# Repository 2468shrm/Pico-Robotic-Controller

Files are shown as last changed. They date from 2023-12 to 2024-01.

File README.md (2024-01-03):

# Pico-Robotic-Controller

A carrier board for a Raspberry Pi Pico (W) for use in FRC robotics. Similar
to the XRP board.

## Disclaimer / Warning

This is an experimental device. Not all interfaces have been fully validated
for proper function. Use at your own risk.

## Introduction (Motivation)

You may assume that this board is indended to compete with the XRP product
from WPI, other developers, and SparkFun. __It is not__. The XRP board is
awesome and I'll likely end up acquiring one (or two) for myself. I have
been working on lo w-cost, roboRIO-like carrier boards for FRC for a couple
of years.

Why create a carrier board like the roboRIO? To enable a lower-cost
prototyping solution. This solution makes it less risky to a costly
than using a roboRIO solution. Breaking a roboRIO means costly replacement
that is sometimes hard to replace. One goal was to provide as many
similar interfaces as possible but cost 25% the budget.

Things I didn't need to do with my use model: support LabVIEW despite being
a team who lives and breaths LabVIEW. I did want to support rapid prototyping
and so exploring circuitpython was a goal; particularly because of the
library support for the STEMMA QT/Qwiic based sensors available from
Adafruit.

## Board Images

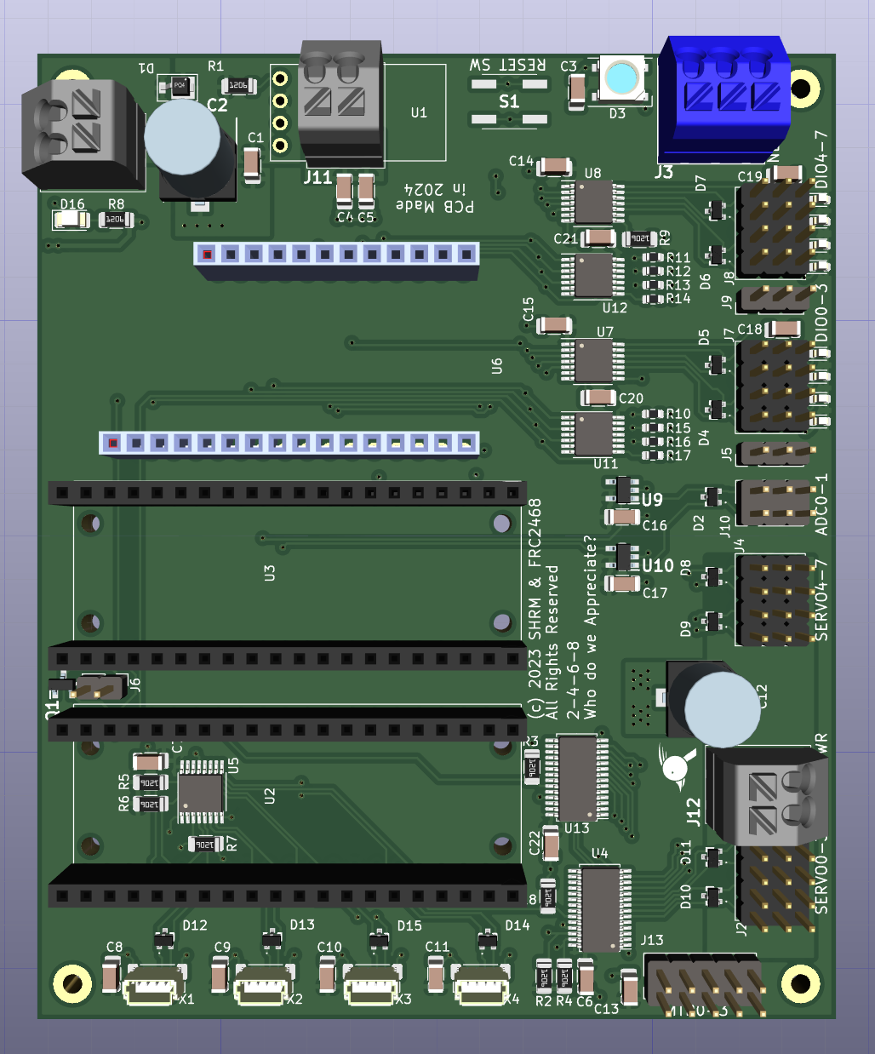
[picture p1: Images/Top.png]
Top View


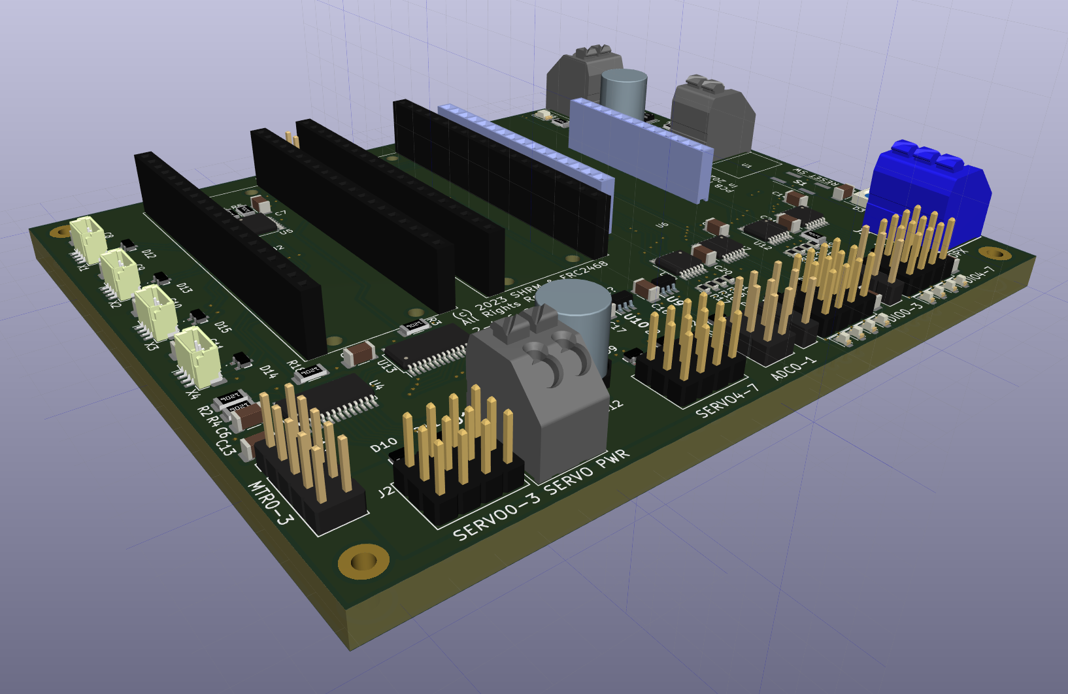
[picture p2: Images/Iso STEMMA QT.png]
Isometric View from the I2C connector corner


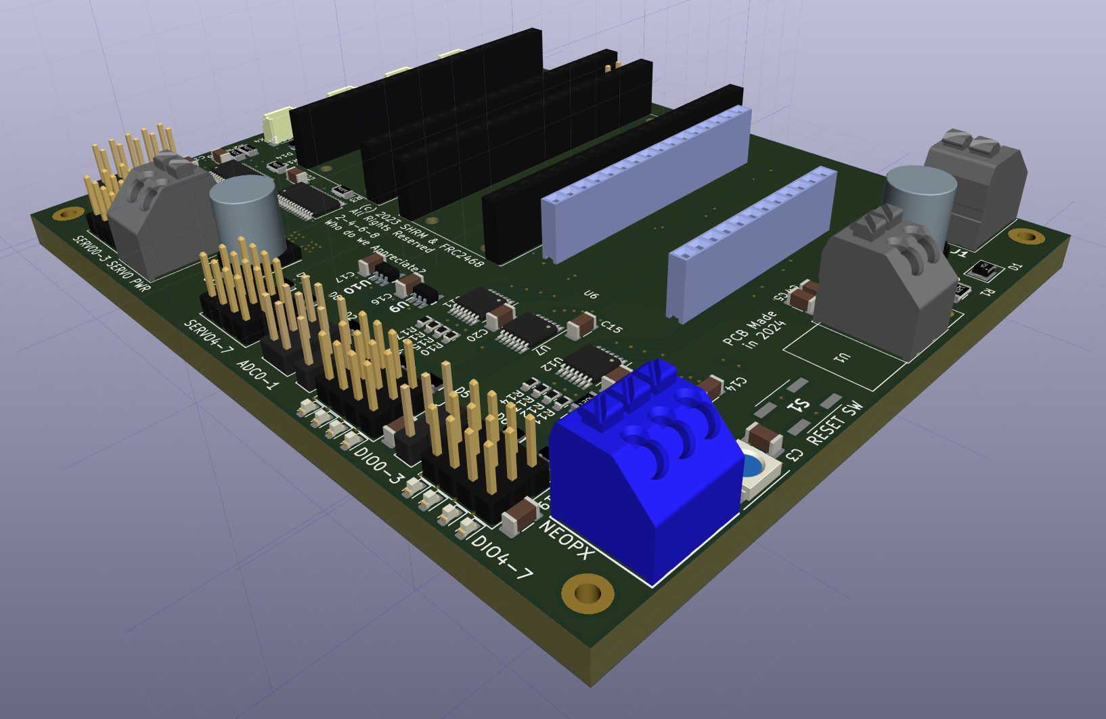
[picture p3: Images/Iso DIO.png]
Isometric View from the digital I/O connector corner


## Board Features

The carrier board has the following interfaces and features.

- RaspberryPi Pico W board
  - Does the thinking
  - Provides WiFi and/or Bluetooth
  - Socketed for replacemnt if needed
- Adafruit Picobell CAN board (optional)
  - Provides CAN connectivity for integration into FRC robots allowing CAN-connected applications (e.g. smart sensors)
- Adafruit Ethernet Featherwing board (optional)
  - Provides Ethernet connectivity for integration into FRC robots allowing Ethernet connected applications (e.g. smart sensors)
- Power
  - 12V Battery input provides main board supply
    - 5V regulator module, OR
    - A connection to external 5V regulator (using WAGO 250-202) connector if the 5V supply current requirements are higher than the module can provide
  - Servo/PWM interface independently powered by an external source
    - Due to the potential need for different voltage and higher current
    - Not needed if connecting to external motor controllers (REV, CTRE, etc.)
- Four (4) STEMMA QT/Qwiic connections provided through a 4-port I2C switch run off the Pico W I2C 1 interface
- Eight (8) Servo PWM interfaces and an additional 8 PWM signals generated by a 16-channel generator connected to the Pico W I2C 0 interface
 - The Servo PWM interace has its own power input; for increased voltage or current for high-torque servo motors
- Two (2) analog input (ADC) ports, 3V maximum
- Eight (8) digital I/O ports, divided into 2 4-pin groups
  - Uses the roboRIO DIO 3-pin interface
  - Each group provides jumper-selectable power (5V or 3.3V)
  - Pico inputs are 3.3V only (maximum) input, with level shifting based on the group's selected power
  - All DIOs have LEDs to indicate logic level (Dark is LOW, Illuminated is HIGH)
- One NEOPIXEL interface for providing visual sensor status or communication
- One on-board single-pixel NEOPIXEL for board status

## Comparison to XRP Board

The XRP board has some significant philospohical and design choices and features.

- XRP was designed with the intent of learning robotics on a small platform, using the WPILib framework
- Includes four motor controllers (1.5A each) integrated on the PCB
- Has a gyro and accelerometer integrated on the PCB
- The connectors are six-position JST (vertical) that integrates digital I/Os for encoders in addition to the M+ and M- motor signals (i.e. not a sensor standard like Qwiic or STEMMA QT)

The PRC does not include any motor controllers on the board. However, it
does provide a 2x5 pin connector and a dedicated PWM generator (I2C bus 0,
address 0x41). The intent is to provide a board with 4 12V, 3.3 A motor
controllers using a separate/dedicated battery input. Providing the capability
to drive four H-Bridges allows for demonstration chassis (skid steer or
Meccanum). This allows replaceable solutions as well as future upgrades for
higher current. Moreover, the PWM / Servo connections allow for use of
a conventional FRC PWM-controlled motor controller.

The PRC provides four STEMMA QT / Qwiic connectors in lieu of a specific set
of sensors (IMU). This allows out use of different sensors dependent on
the application.

The PRC also has CAN and Ethernet connectivity in addition to the WiFi and
BlueTooth provided by the Pice W board.

Differences between the roboRIO, XPR, and PRC boards.
<table>
  <tr style="background-color:#404040">
    <th>Interface / Feature</th>
    <th>RoboRIO</th>
    <th>XRP</th>
    <th>SHRH's Board</th>
  </tr>
  <tr>
    <td>Processing</td>
    <td>Zinq</td>
    <td>RPi Pico W</td>
    <td>RPi Pico W</td>
  </tr>
  <tr>
    <td>Ethernet</td>
    <td>1 Gb</td>
    <td><code>&#8212;</code></td>
    <td>Via 10/100 Mb FeatherWing</td>
  </tr>
  <tr>
    <td>WiFi</td>
    <td>Via OpenMesh</td>
    <td>Y</td>
    <td>Y</td>
  </tr>
  <tr>
    <td>USB Host</td>
    <td>Y</td>
    <td><code>&#8212;</code></td>
    <td><code>&#8212;</code></td>
  </tr>
  <tr>
    <td>CAN</td>
    <td>Y</td>
    <td><code>&#8212;</code></td>
    <td>Via Picobell CAN board</td>
  </tr>
  <tr>
    <td>Relay</td>
    <td>Y</td>
    <td><code>&#8212;</code></td>
    <td><code>&#8212;</code></td>
  </tr>
  <tr>
    <td>Digital I/O</td>
    <td>10 + MXP</td>
    <td><code>&#8212;</code></td>
    <td>8</td>
  </tr>
  <tr>
    <td>ADC</td>
    <td>4</td>
    <td><code>&#8212;</code></td>
    <td>2</td>
  </tr>
  <tr>
    <td>I2C</td>
    <td>2</td>
    <td><code>&#8212;</code></td>
    <td><code>&#8212;</code></td>
  </tr>
  <tr>
    <td>STEMMA QT / Qwiic</td>
    <td><code>&#8212;</code></td>
    <td>4</td>
    <td>4</td>
  </tr>
  <tr>
    <td>SPI</td>
    <td>2</td>
    <td><code>&#8212;</code></td>
    <td><code>&#8212;</code></td>
  </tr>
  <tr>
    <td>RS-232</td>
    <td>1</td>
    <td><code>&#8212;</code></td>
    <td><code>&#8212;</code></td>
  </tr>
  <tr>
    <td>Gyro</td>
    <td>Y</td>
    <td>6 DOF IMU (LSM6DSO)</td>
    <td><code>&#8212;</code></td>
  </tr>
  <tr>
    <td>Status LEDs</td>
    <td>Y</td>
    <td>Pico W LED</td>
    <td>Y (NEOPIXEL) + Pico W LED</td>
  </tr>
  <tr>
    <td>NEOPIXEL String</td>
    <td>2 via PWM outputs</td>
    <td><code>&#8212;</code></td>
    <td>Y</td>
  </tr>
  <tr>
    <td>Low-Current Motor Control</td>
    <td><code>&#8212;</code></td>
    <td>4</td>
    <td>4 on sidecar board</td>
  </tr>
  <tr>
    <td>Per H-Bridge Max Current</td>
    <td><code>&#8212;</code></td>
    <td>1.5 A</td>
    <td>3.3 A</td>
  </tr>
  <tr>
    <td>I/Os Per Motor Interface</td>
    <td><code>&#8212;</code></td>
    <td>2 (equivalent of STEMMA per motor)</td>
    <td><code>&#8212;</code></td>
  </tr>
  <tr>
    <td>Reset Button</td>
    <td>Y</td>
    <td>Y</td>
    <td>Y</td>
  </tr>
  <tr>
    <td>Power In</td>
    <td>12 V</td>
    <td>5-11 V</td>
    <td>12 V</td>
  </tr>
  <tr>
    <td>Power Conntector</td>
    <td>Sauro</td>
    <td>Barrel</td>
    <td>Wago 250-202</td>
  </tr>
  <tr>
    <td></td>
    <td></td>
    <td></td>
    <td></td>
  </tr>
</table>

Differences between the XRP and PRC pin usage and functions.

<table>
  <tr style="background-color:#404040">
    <th>Pin</th>
    <th>Pico W Alternatives</th>
    <th>XRP Interface</th>
    <th>XRP Function</th>
    <th>PRC Board</th>
  </tr>
  <tr>
    <td>GPIO 0</td>
    <td>U0 TX / SDA0 / MISO0</td>
    <td rowspan="4">Motor 3</td>
    <td>Encoder A</td>
    <td>DIO 0</td>
  </tr>

  <tr>
    <td>GPIO 1 </td>
    <td>U0 RX / SCL0 / CS0</td>
    <td>Encoder B</td>
    <td>DIO 1</td>
  </tr>
  <tr>
    <td>GPIO 2</td>
    <td>SDA1 / SCK0</td>
    <td>Phase</td>
    <td>PWM Gen SDA</td>
  </tr>
  <tr>
    <td>GPIO 3 </td>
    <td>SCL1 / MOSI0</td>
    <td>Enable</td>
    <td>PWM Gen SCL</td>
  </tr>
  <tr>
    <td>GPIO 4 </td>
    <td>U1 TX / SDA0 / MISO0</td>
    <td rowspan="4">Left Motor</td>
    <td>Encoder A</td>
    <td>I2C Switch SDA</td>
  </tr>
  <tr>
    <td>GPIO 5</td>
    <td>U1 RX / SCL0 / CS0</td>
    <td>Encoder B</td>
    <td>I2C Switch SCL</td>
  </tr>
  <tr>
    <td>GPIO 6</td>
    <td>SDA1 / SCK0</td>
    <td>Phase</td>
    <td>DIO 2</td>
  </tr>
  <tr>
    <td>GPIO 7</td>
	<td>SCL1 / MOSI0</td>
    <td>Enable</td>
    <td>DIO 3</td>
  </tr>
  <tr>
    <td>GPIO 8</td>
    <td>U1 TX / SDA0 / MISO1</td>
    <td rowspan="4">Motor 4</td>
    <td>Encoder A</td>
    <td>DIO 4</td>
  </tr>
  <tr>
    <td>GPIO 9</td>
    <td>U1 RX / SCL0 / CS1</td>
    <td>Encoder B</td>
    <td>DIO 5</td>
  </tr>
  <tr>
    <td>GPIO 10</td>
    <td>SDA1 / SCK1</td>
    <td>Phase</td>
    <td>DIO 6</td>
  </tr>
  <tr>
    <td>GPIO 11</td>
 	<td>SCL1 / MOSI1</td>
    <td>Enable</td>
    <td>DIO 7</td>
  </tr>
  <tr>
    <td>GPIO 12</td>
	<td>U0 TX / SDA0 / MISO1</td>
    <td rowspan="4">Right Motor</td>
    <td>Encoder A</td>
    <td>PWM Gen Enable</td>
  </tr>
  <tr>
    <td>GPIO 13</td>
	<td>U0 RX / SCL0 / CS1</td>
    <td>Encoder B</td>
    <td>Reset Switch</td>
  </tr>
  <tr>
    <td>GPIO 14</td>
 	<td>SDA1 / SCK1</td>
    <td>Phase</td>
    <td>not connected</td>
  </tr>
  <tr>
    <td>GPIO 15</td>
    <td>SCL1 / MOSI1</td>
    <td>Enable</td>
    <td>SPI CS (Ethernet)</td>
  </tr>
  <tr>
    <td>GPIO 16</td>
    <td>U0 TX / SDA0 / MISO0</td>
    <td>Servo 1</td>
    <td>Signal</td>
    <td>SPI MISO</td>
  </tr>
  <tr>
    <td>GPIO 17</td>
    <td>U0 RX / SCL0 / CS0</td>
    <td>Servo 2</td>
    <td>Signal</td>
    <td>NEOPIXEL (board)</td>
  </tr>
  <tr>
    <td>GPIO 18</td>
    <td>SDA1 / SCK0</td>
    <td rowspan="2">IMU / Qwiic</td>
    <td>SDA</td>
    <td>SPI SCK</td>
  </tr>
  <tr>
    <td>GPIO 19</td>
    <td>SCL1 / MOSI0</td>
    <td>SCL</td>
    <td>SPI MOSI</td>
  </tr>
  <tr>
    <td>GPIO 20</td>
    <td>SDA0</td>
    <td rowspan="2">Range</td>
    <td>Trigger</td>
    <td>SPI CS (CAN)</td>
  </tr>
  <tr>
    <td>GPIO 21</td>
    <td>SCL0</td>
    <td>Echo</td>
    <td>SPI INT (CAN)</td>
  </tr>
  <tr>
    <td>GPIO 22</td>
    <td></td>
    <td></td>
    <td>User button / extra</td>
    <td>NEOPIXEL (String)</td>
  </tr>
  <tr>
    <td>GPIO 26</td>
    <td>SDA1 / ADC0</td>
    <td rowspan="2">Line Follower</td>
    <td>Left</td>
    <td>ADC 0</td>
  </tr>
  <tr>
    <td>GPIO 27</td>
    <td>SCL1 / ADC1</td>
    <td>Right</td>
    <td>ADC 1</td>
  </tr>
  <tr>
    <td>GPIO 28</td>
    <td></td>
    <td></td>
    <td>VIN_meas / extra</td>
    <td>not connected</td>
  </tr>
</table>

## PRC Board Detail / Theory of Operation

The following describes the PRC board components, features, and 

When exploring the board's detail and function, it may be helpful to refer to
the board's schematic ([Link](https://github.com/2468shrm/Pico-Robotic-Controller/blob/main/Images/Pico%20Robotic%20Controller%20Schematic.pdf)).

### Main Power / Battery Input

The power system has the following components:
- +BATT - The main power supply (+BATT) is connected to J1, a 2-position WAGO 250 series connector. The typical use is a 12V battery or power supply.
- +12V - Connected to +BATT through a diode-capacitor filter. The intent of the filter is to avoid brownouts on the robot from affecting board performance.
- +5V - The Pico W uses a 5V source normally supplied by USB's VBUS. However, the board provides a 5V source. This is done via either installing a 5V 3A regulator module ([Amazon Link](https://www.amazon.com/gp/product/B08JZ5FVLC)), or by installing a 2-position WAGO 250-series connector (J11) and providing an external 5V supply.  The external solution would be used only in situations where 3A is insufficient (e.g. a very long NEOPIXEL strip).
- SERVO_VDD - A dedicated power input is provided for use cases involving servo motors. This is required since the +5V supply is limited to 3A which may not be sufficient for servo motors in stall. Moreover, while servo motors may operate at 5V, they're better at operating at higher voltages (6V).
- VSYS - VSYS is a pin on the Pico W board that is sourced from VBUS through a Schottky diode, but this is only functional when the VBUS is connected.  VSYS is also soured by a PFET (Q1, a DMG2305UX-13) as recommended by the Pico W datasheet ([Raspberry Pi Pico W Datasheet](https://datasheets.raspberrypi.com/picow/pico-w-datasheet.pdf#page=15)). Refer to sections 3.4 and 3.5 of the datasheet for details. This allows a computer connected via VBUS at the same time the board is powred by +BATT (or the J11 external source).
- VBUS - The USB OTG's power pin. Note that J6 is provided (and needs to have a jumper installed)  in order to source VBUS from the board's +5V supply when the USB OTG interface is being used in HOST mode.

### Processing and Communications
The PRC is intended to serve as a low-cost roboRIO.  To that end it includes
computation and communication at the heart of the system.

#### Pi Pico W
The PRC includes a socket to install a Raspberry Pi Pico W board. This
is in component designator U2.

#### CAN  
The PRC includes a socket to install an Adafruit Picowbell board
([link](https://www.adafruit.com/product/5728)). This board uses a Microchip
MCP2515 SPI to CAN device. This is an optional device; the PRC can opeate with
CAN, Ethernet, Both, or none.

The CAN and Ethernet boards share the same SPI MOSI, MISO, and SCK signals, but
have independent chips selects (and in the case of CAN a separate interrupt
signal).

#### Ethernet
The PRC includes a socket to install an Adafruit Ethernet Featherwing
([link](https://www.adafruit.com/product/3201)).This is an optional device;
the PRC can opeate with CAN, Ethernet, Both, or none.

The CAN and Ethernet boards share the same SPI MOSI, MISO, and SCK signals, but
have independent chips selects.

### Sensors
There are multiple digital and analog sensor connection methods used with the PRC
board. These include a number of I2C interfaces that use the Qwiic/STEMMA QT format,
analog inputs, and digital I/Os.

#### Qwiic / STEMMA QT
There are four (4) Qwiic/STEMMA QT connectors. These connectors (X1-X4) connect
to the Pico W I2C bus 1 via an TCA9546 4-port I2C switch/mux (I2C bus 1
address 0x70).

The Qwiic/STEMMA QT connector provide the two I2C signals (each connector coming
from one dedicated output of the I2C mux/switch), 3.3V, and GND. This format
connector assumes the attached device provides the SDA/SCL pull ups and any local
level shifting to the sensor. It also assumes the board provides 3.3V conversion
to the sensor used. Each Qwiic/STEMMA QT connection may chain multiple sensors
provided their I2C addresses do not collide and the signal integrity of the I2C
signals is maintained.

The Qwiic/STEMMA QT to mux/switch channel is provided in the following table.
<table>
  <tr style="background-color:#404040">
    <th>Channel</th>
    <th>Interface</th>
    <th>Function / # </th>
  </tr>
  <tr>
    <td>0</td>
    <td rowspan="2">X1</td>
    <td>SDA0</td>
  </tr>
  <tr>
    <td>1</td>
    <td>SCL0</td>
  </tr>
  <tr>
    <td>2</td>
    <td rowspan="2">X2</td>
    <td>SDA1</td>
  </tr>
  <tr>
    <td>3</td>
    <td>SCL1</td>
  </tr>
  <tr>
    <td>4</td>
    <td rowspan="2">X3</td>
    <td>SDA3</td>
  </tr>
  <tr>
    <td>5</td>
    <td>SCL3</td>
  </tr>
  <tr>
    <td>6</td>
    <td rowspan="2">X4</td>
    <td>SDA2</td>
  </tr>
  <tr>
    <td>7</td>
    <td>SCL2</td>
  </tr>
</table>

#### ADC / Analog Input
There are two (2) analog input pins that connect to the Pico W ADC0 and ADC1
pins. The board buffers the input signals between pin and Pico W ADC inputs with
a unity gain opamp.  This is done to provide the highest accuracy while allowing
the use of sensors with larger output impedances.

The ADCs use a 3x2 pin header, and uses the same pin layout as the roboRIO's AIN
connections; signal, power, and ground. Ground is closest to the board edge and
power in the middle. The power pin voltage is 3.3V since the Pico W ADC range is
0 to 3.3 V.

#### Digital Input/Output (DIO)
There are eight (8) DIOs arranged in two groups of four, DIO0-3 and DIO4-7.
Each group has an independent level shifter (TXS0104E). The level shifter
includes 10 kΩ pull ups. Since the Pico W has 3.3V (only) I/Os, the VCCA of both
level shifters use 3.3 V. However the VCCB of the external side of each level
shifter is set by an external jumper (J5 for DIO0-3 and J9 for DIO4-7) and
can be set to either 3.3 V or 5 V.

Each DIO group uses a 3x4 pin header, and uses the same pin layout as the roboRIO's
DIO connections; signal, power, and ground. Ground is closest to the board edge
and power in the middle. The power pin voltage is the same voltage pdovided
to the VCCB of the level shifter.

### Motor Control
There are two main interfaces for controlling motors and servos.
1. PWM/Servo interface. Eight (8) conventional PWM/Servo connections.
1. There is also a dedicated motor control interface to connect to a custom, 4 channel, low-current, motor driver board.

#### PWM/Servo

The PWM/Servo interface uses the first 8 channels of a PCA9685 PWM generator
(I2C bus 0, I2C address 0x40).

If using the PWM/Servo interface for servo control, connect the J12 connector
(supplying SERVO_VDD) to an external power supply. This is not needed if the
PWM/Servo interface is being used to connect to external motor controllers
from REV, CTRE, etc.

<table>
  <tr style="background-color:#404040">
    <th>Channel</th>
    <th>Interface</th>
    <th>Function / # </th>
  </tr>
  <tr>
    <td>0</td>
    <td rowspan="8">PWM Block</td>
    <td>PWM 0</td>
  </tr>
  <tr>
    <td>1</td>
    <td>PWM 1</td>
  </tr>
  <tr>
    <td>2</td>
    <td>PWM 2</td>
  </tr>
  <tr>
    <td>3</td>
    <td>PWM 3</td>
  </tr>
  <tr>
    <td>4</td>
    <td>PWM 4</td>
  </tr>
  <tr>
    <td>5</td>
    <td>PWM 5</td>
  </tr>
  <tr>
    <td>6</td>
    <td>PWM 6</td>
  </tr>
  <tr>
    <td>7</td>
    <td>PWM 7</td>
  </tr>
  <tr>
    <td>8-15</td>
    <td colspan="2">Unused</td>
  </tr>
</table>

#### Motor Control

The motor control interface uses the first 8 channels of a dedicated PCA9685 PWM
generator (I2C bus 0, I2C address 0x41).

These connect to the motor controller board and drive four (4) instances of a TI
DRV8870 3.5 A motor controller. This board is intended to be used in FTC-class
robots or for classroom and learning (not competition) use. 

The DRV8870 has 2 signal inputs per IC (IN1, IN2).  The motor controller
operates as follows:

<table>
  <tr style="background-color:#404040">
    <th>IN1</th>
    <th>IN2</th>
    <th>OUT 1</th>
    <th>OUT 2</th>
    <th>Motor Action </th>
  </tr>
  <tr>
    <td>0</td>
    <td>0</td>
    <td>High-Z</td>
    <td>High-Z</td>
    <td><u>Coast</u><br />Current direction remains and flows through reverse body diodes of H-bridge. </td>
  </tr>
  <tr>
    <td>0</td>
    <td>1</td>
    <td>GND</td>
    <td>VDD</td>
    <td><u>Reverse</u><br />Current flows from OUT 2 to OUT 1.</td>
  </tr>
  <tr>
    <td>1</td>
    <td>0</td>
    <td>VDD</td>
    <td>GND</td>
    <td><u>Forward</u><br /> Current flows from OUT 1 to OUT 2.</td>
  </tr>
  <tr>
    <td>1</td>
    <td>1</td>
    <td>GND</td>
    <td>GND</td>
    <td><u>Brake</u><br />Current recirculates between low-side H-bridge.</td>
  </tr>
</table>

Note: When pulse width modulating the IN1 & IN2 to provide speed control
of the attached motors, it is important to realize that operating in coast
or brake modes is important to consider.

In coast mode, the motor coasts when both IN1 and IN2 are 0. This matches
the normal signal polarity of a PWM signal (high represents active).

<table>
  <tr style="background-color:#404040">
    <th>Mode</th>
    <th>Direction</th>
    <th>IN1</th>
    <th>IN2</th>
  </tr>
  <tr>
    <td rowspan="2">Coast</td>
    <td>Forward</td>
    <td>PWM'd</td>
    <td>0</td>
  </tr>
  <tr>
    <td>Reverse</td>
    <td>0</td>
    <td>PWM'd</td>
  </tr>
</table>

The PWM will drive the motor fur the duration of the high time of the duty
cycle and coast through the low time.

In brake mode, the motor breaks when both IN1 and IN2 are 1. This is opposite
the normal signal polarity of a PWM signal, so the signal generation needs
to be inverted and the low-time needs to represent the desired fraction of
the output. Also, the PWM'd input signal must be swapped so that the
correct direction is maintained.

<table>
  <tr style="background-color:#404040">
    <th>Mode</th>
    <th>Direction</th>
    <th>IN1</th>
    <th>IN2</th>
  </tr>
  <tr>
    <td rowspan="2">Coast</td>
    <td>Forward</td>
    <td>1</td>
    <td>inverse PWM'd</td>
  </tr>
  <tr>
    <td>Reverse</td>
    <td>Inverse PWM'd</td>
    <td>1</td>
  </tr>
</table>

Also note this is a not the PWM encoding used for servo controls. The PWM
modulation applied to IN1 and IN2 is full duty cycle of the signal's period
(not the first 2 ms of 20 ms signal).

I2C bus 0, address 0x41
<table>
  <tr style="background-color:#404040">
    <th>Channel</th>
    <th>Interface</th>
    <th>Function / # </th>
  </tr>
  <tr>
    <td>0</td>
    <td rowspan="2">M0</td>
    <td>IN1</td>
  </tr>
  <tr>
    <td>1</td>
    <td>IN2</td>
  </tr>
  <tr>
    <td>2</td>
    <td rowspan="2">M1</td>
    <td>IN1</td>
  </tr>
  <tr>
    <td>3</td>
    <td>IN2</td>
  </tr>
  <tr>
    <td>4</td>
    <td rowspan="2">M2</td>
    <td>IN1</td>
  </tr>
  <tr>
    <td>5</td>
    <td>IN2</td>
  </tr>
  <tr>
    <td>6</td>
    <td rowspan="2">M3</td>
    <td>IN1</td>
  </tr>
  <tr>
    <td>7</td>
    <td>IN2</td>
  </tr>
  <tr>
    <td>8-15</td>
    <td colspan="2">Unused</td>
  </tr>
</table>

### Status

The PRC provides simple interfaces for visual status.

#### NEOPIXEL on PCB

A single NEOPIXEL device is mounted on the board. This is intended to provide
visual status while developing code or tuning algodrithms and mechanisms.

#### NEOPIXEL Strip

A 3-position 250-series WAGo connector is provided to connect a NEOPIXEL strip
to the board. This is intended to provide visual status for distant observation.
The most common use case being robot to driver status across the FRC field.

### PCB Layer Usage

The PRC PCB uses four layers primarily to keep power distribution as clean
as possible. The layers are used as described in the following table. Each
layer label includes a link to the layer's image.

<table>
  <tr style="background-color:#404040">
    <th>Layer</th>
    <th>Use</th>
  </tr>
  <tr>
    <td rowspan="3"><a href="https://github.com/2468shrm/Pico-Robotic-Controller/blob/main/Images/F.Cu.png">F.Cu</a></td>
    <td>+3V3 fill (main +3.3V plane)</td>
  </tr>
  <tr>
    <td>Signal routing</td>
  </tr>
  <tr>
    <td>Component placement (SMT)</td>
  </tr>
  <tr>
    <td rowspan="2"><a href="https://github.com/2468shrm/Pico-Robotic-Controller/blob/main/Images/In1.Cu.png">In1.Cu</a></td>
    <td>+BATT fill (main battery plane)</td>
  </tr>
  <tr>
    <td>Signal routing</td>
  </tr>
  <tr>
    <td rowspan="3"><a href="https://github.com/2468shrm/Pico-Robotic-Controller/blob/main/Images/In2.Cu.png">In2.Cu</a></td>
    <td>+5V fill (main +5V plane)</td>
  </tr>
  <tr>
    <td>VIOA and VIOB (DIO power)</td>
  </tr>
  <tr>
    <td>Signal routing (across CPU, CAN, Eth modules)</td>
  </tr>
  <tr>
    <td rowspan="2"><a href="https://github.com/2468shrm/Pico-Robotic-Controller/blob/main/Images/B.Cu.png">B.Cu</a></td>
    <td>Ground fill (main ground plane)</td>
  </tr>
  <tr>
    <td>+5V fill (small fills and 5V traces)</td>
  </tr>
</table>

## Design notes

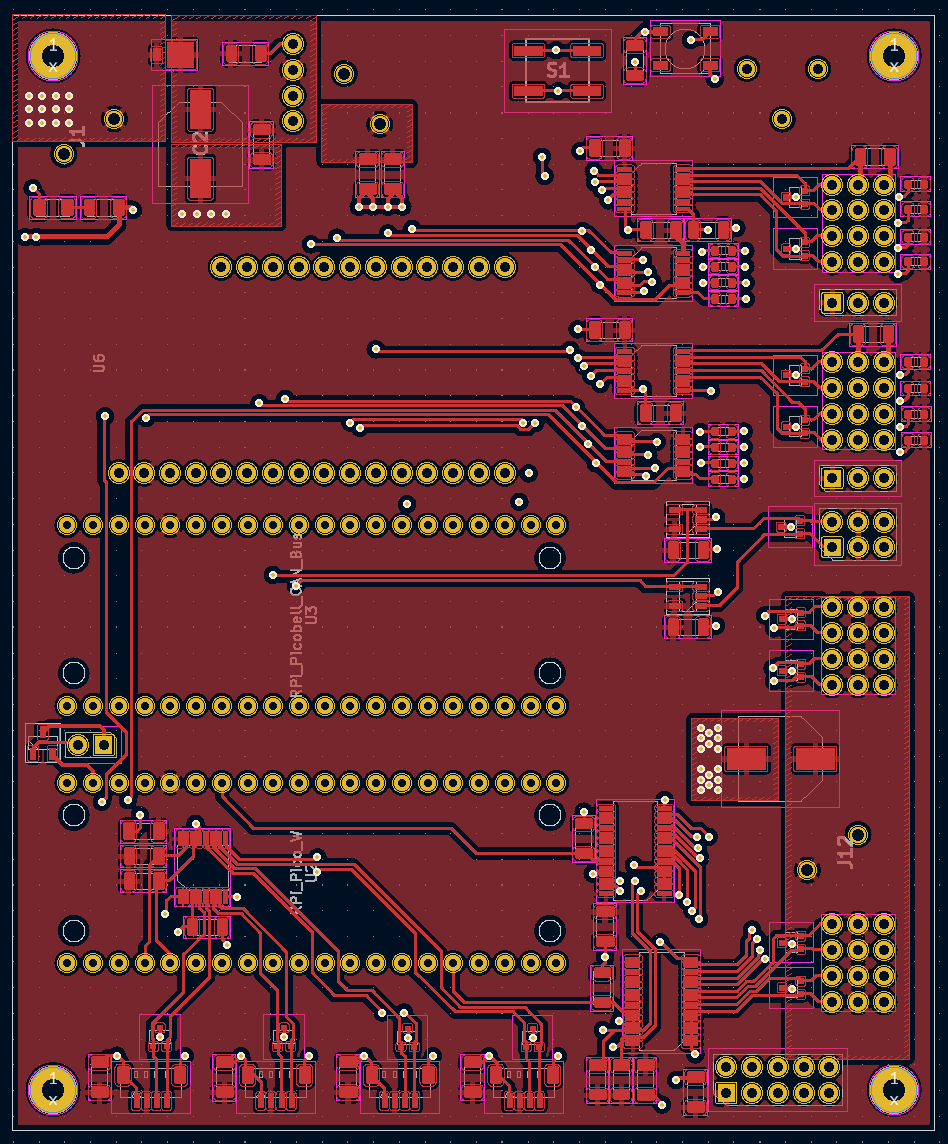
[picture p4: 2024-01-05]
Images/F.Cu.png

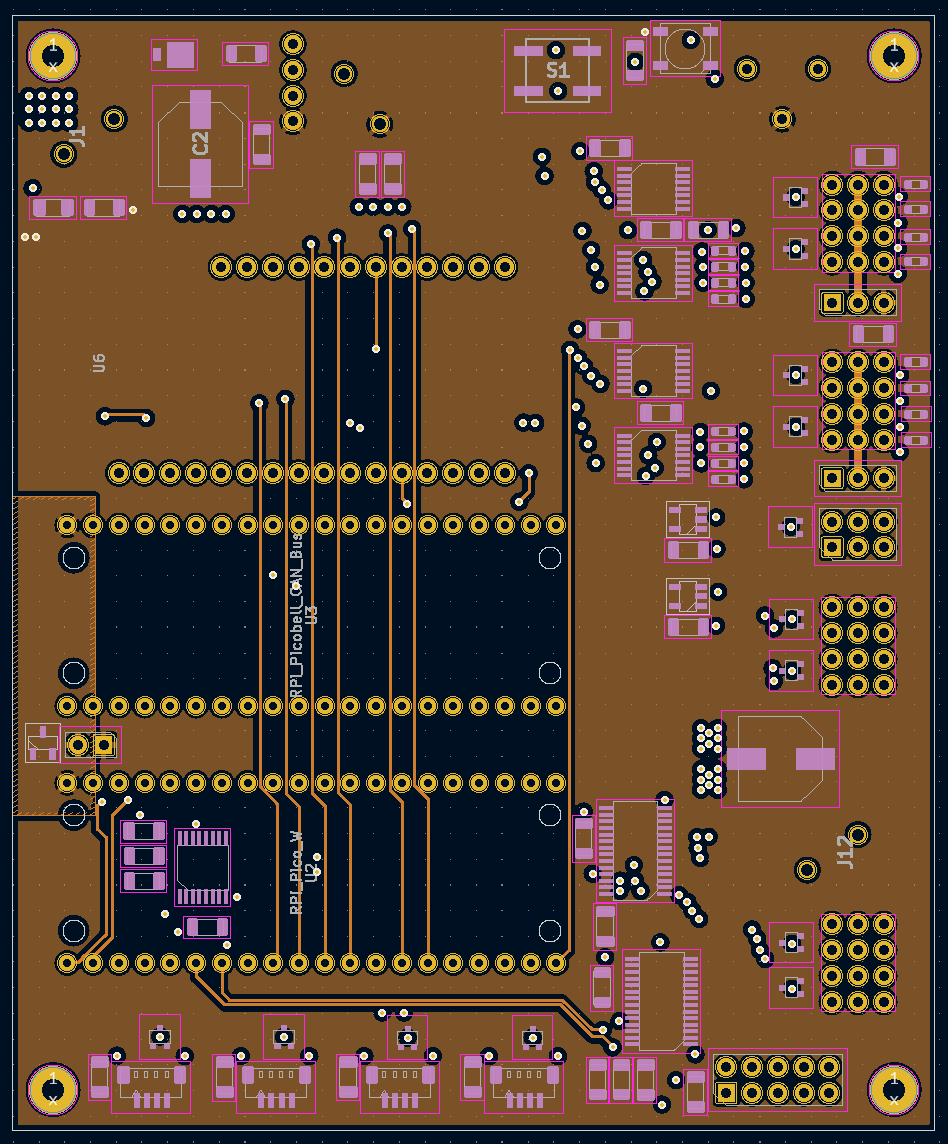
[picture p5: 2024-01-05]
Images/In2.Cu.png

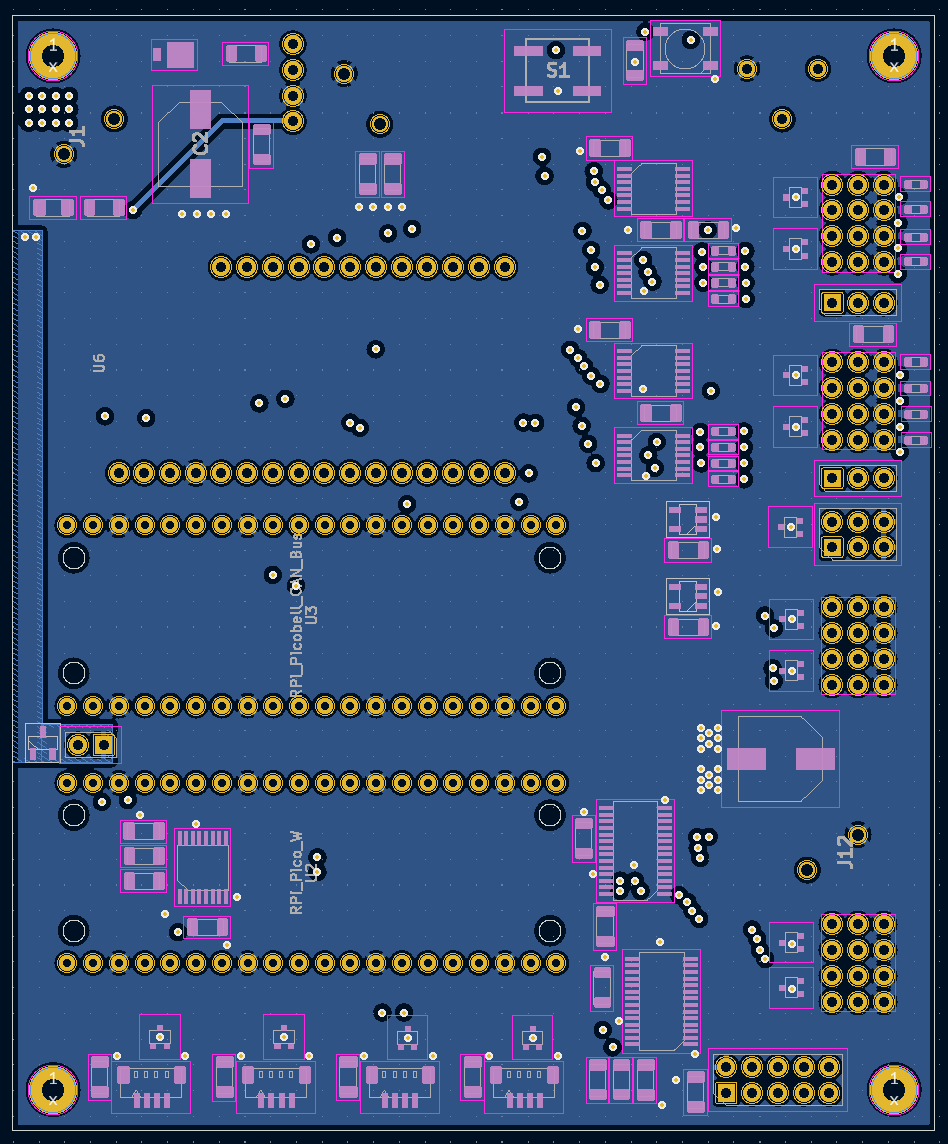
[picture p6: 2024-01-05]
Images/B.Cu.png

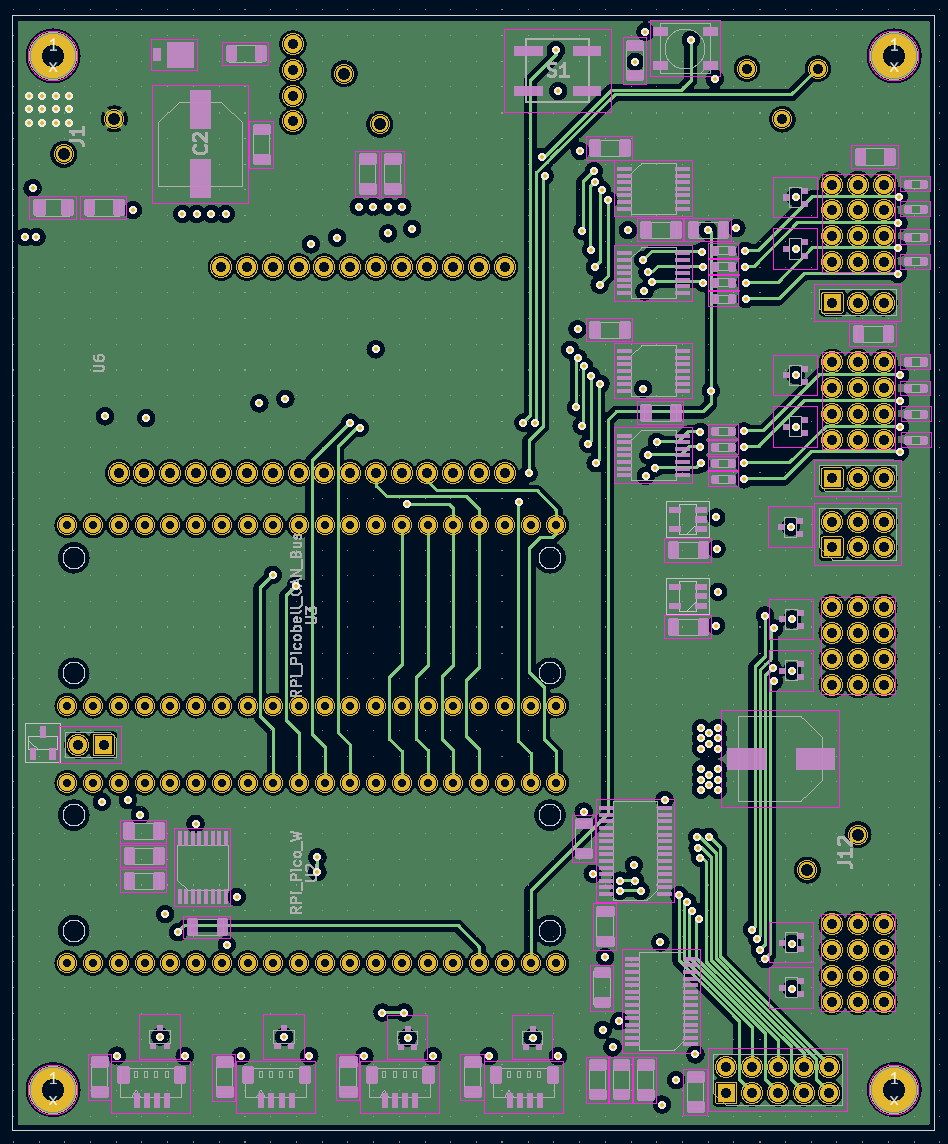
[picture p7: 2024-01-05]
Images/In1.Cu.png

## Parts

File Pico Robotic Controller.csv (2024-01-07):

Comment | Designator | Footprint | LCSC
10u | C1,C4,C18,C19 | Capacitor_SMD:C_1206_3216Metric | C14860
470u | C2,C12 | Appreciate:CAPAE830X1050N | C340767
0.1u | C3,C5,C6,C7,C8,C9,C10,C11,C13,C14,C15,C16,C17,C20,C21,C22 | Capacitor_SMD:C_1206_3216Metric | C24497
LED | D16 | LED_SMD:LED_1206_3216Metric | C375581
LED | D17,D18,D19,D20,D21,D22,D23,D24 | LED_SMD:LED_0603_1608Metric | C779453
PESD1CAN-UX | D2,D4,D5,D6,D7,D8,D9,D10,D11,D12,D13,D14,D15 | Appreciate:PESD1CANUX | C907839
WS2812B | D3 | LED_SMD:LED_WS2812B_PLCC4_5.0x5.0mm_P3.2mm | C2761795
DMG2305UX-13 | Q1 | Appreciate:SOT96P240X120-3N | C144153
5K1 | R1,R2,R3,R4,R5,R6,R7,R9,R18 | Resistor_SMD:R_1206_3216Metric | C118077
13 | R10,R11,R12,R13,R14,R15,R16,R17 | Resistor_SMD:R_0603_1608Metric | C365384
100 | R8 | Resistor_SMD:R_1206_3216Metric | C17901
74HC14 | U11,U12 | Package_SO:TSSOP-14_4.4x5mm_P0.65mm | C2866133
PCA9685PW | U4,U13 | Package_SO:TSSOP-28_4.4x9.7mm_P0.65mm | C2678753
TCA9546 | U5 | Package_SO:TSSOP-16_4.4x5mm_P0.65mm | C201653
TXS0104EPW | U7,U8 | Package_SO:TSSOP-14_4.4x5mm_P0.65mm | C44955
APX321WG-7 | U9,U10 | Appreciate:SOT95P285X145-5N | C151412
STEMMA_I2C_QT | X1,X2,X3,X4 | Connector_JST:JST_SH_BM04B-SRSS-TB_1x04-1MP_P1.00mm_Vertical | C545725

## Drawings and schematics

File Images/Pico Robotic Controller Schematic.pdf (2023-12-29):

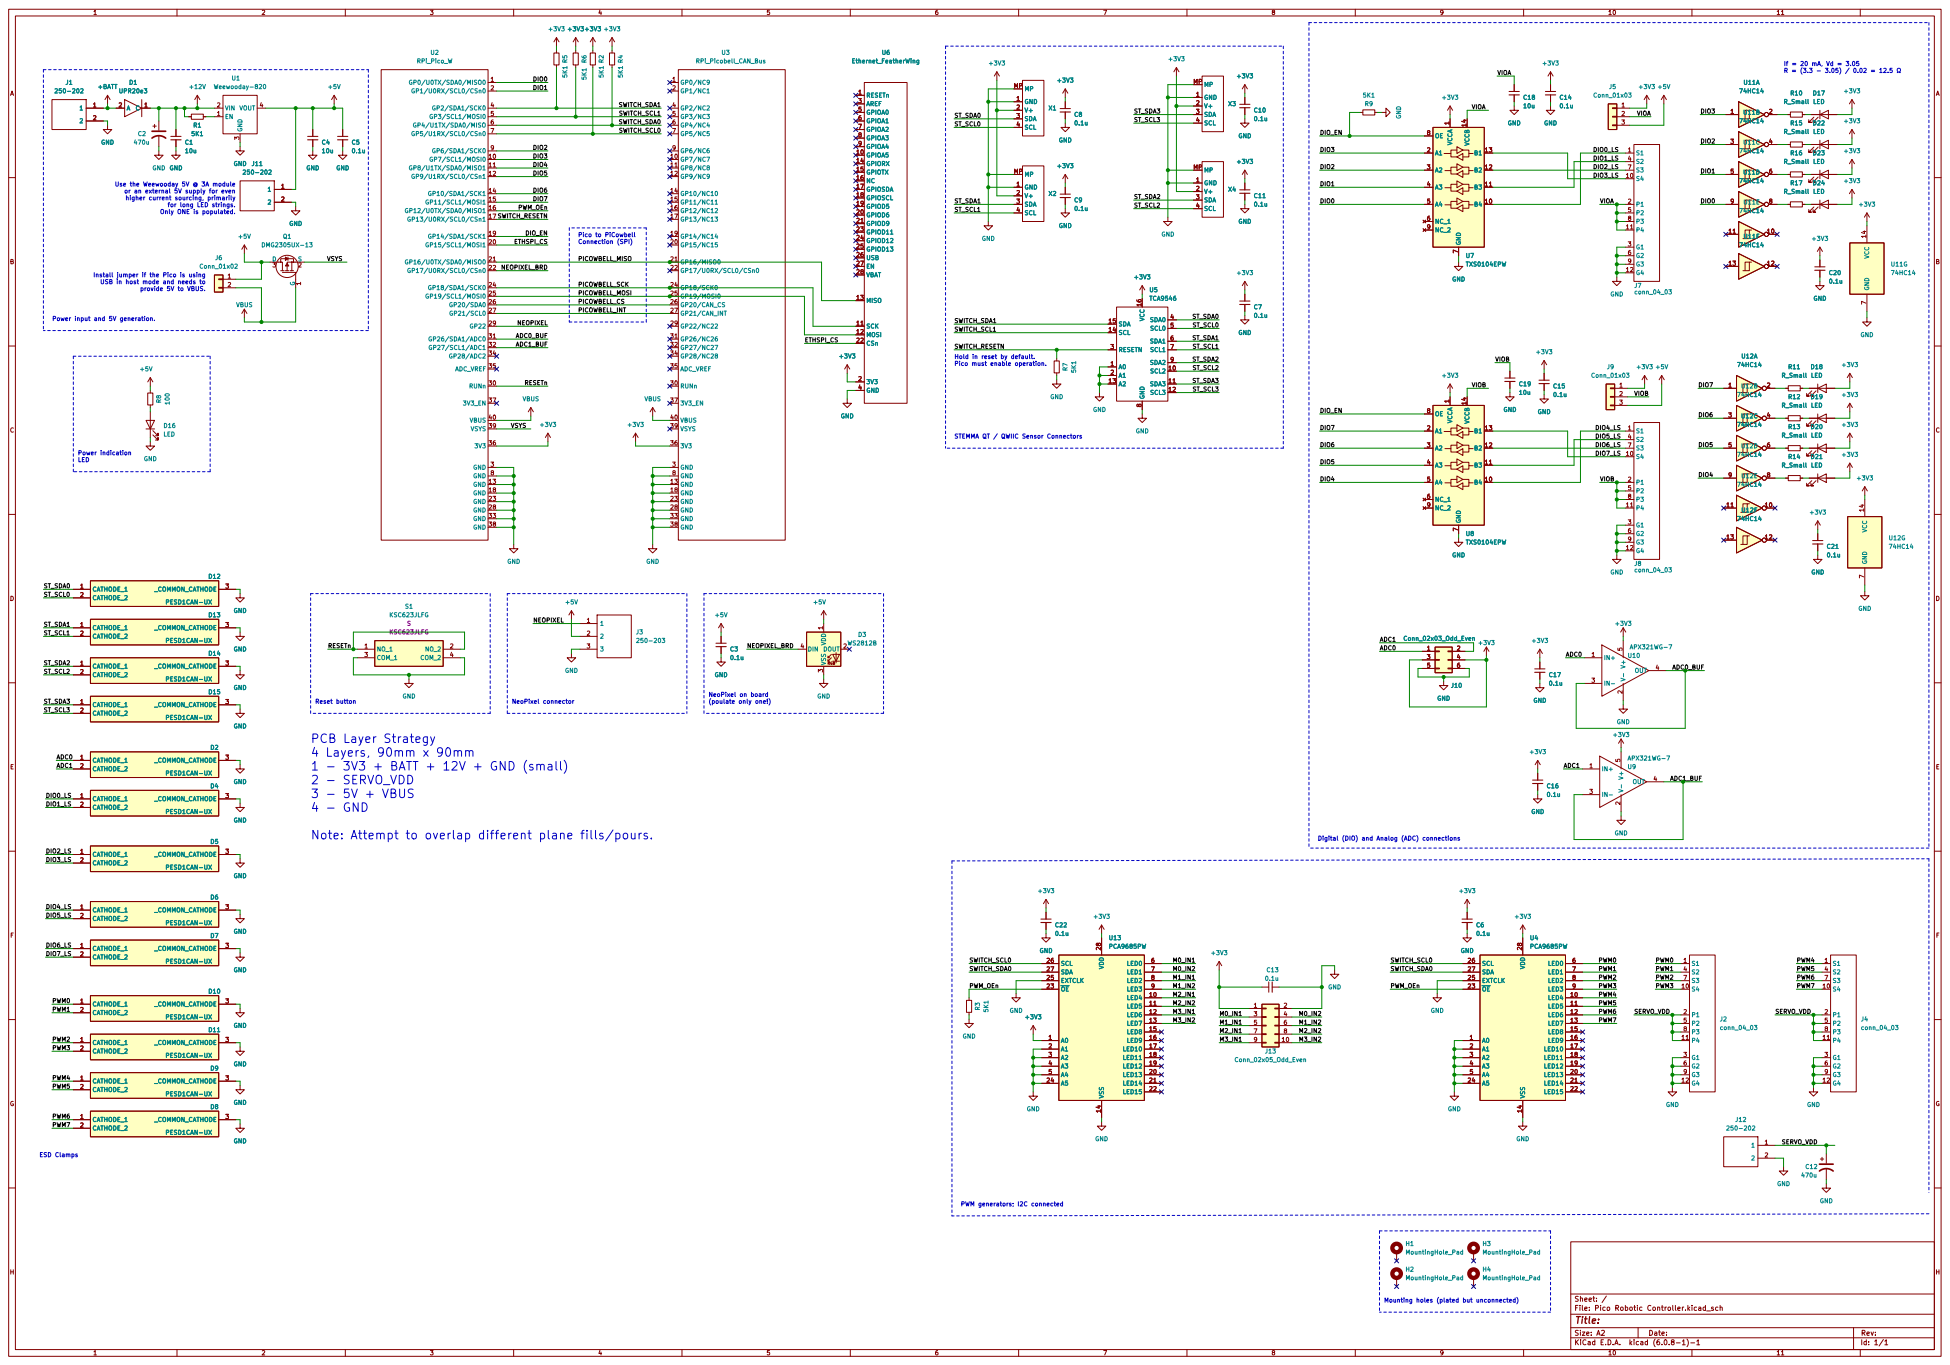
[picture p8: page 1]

0.1u +3V3 GND
GND 1 V+ 2 SDA 3 SCL 4 MP MP

X1 GND 1 V+ 2 SDA 3 SCL 4 MP MP
ST_SCL0 ST_SDA0 ST_SCL1 ST_SDA1

GND

Use the Weewooday 5V @ 3A module
or an external 5V supply for even
higher current sourcing, primarily

for long LED strings.
Only ONE is populated.

Pico to PiCowbell Connection (SPI)

provide 5V to VBUS. Power indication

Install jumper if the Pico is using USB in host mode and needs to

SWITCH_RESETN
STEMMA QT / QWIIC Sensor Connectors Hold in reset by default.
Pico must enable operation.

Note: Attempt to overlap different plane fills/pours.

Digital (DIO) and Analog (ADC) connections

Mounting holes (plated but unconnected)

File: Pico Robotic Controller.kicad_sch Sheet: /

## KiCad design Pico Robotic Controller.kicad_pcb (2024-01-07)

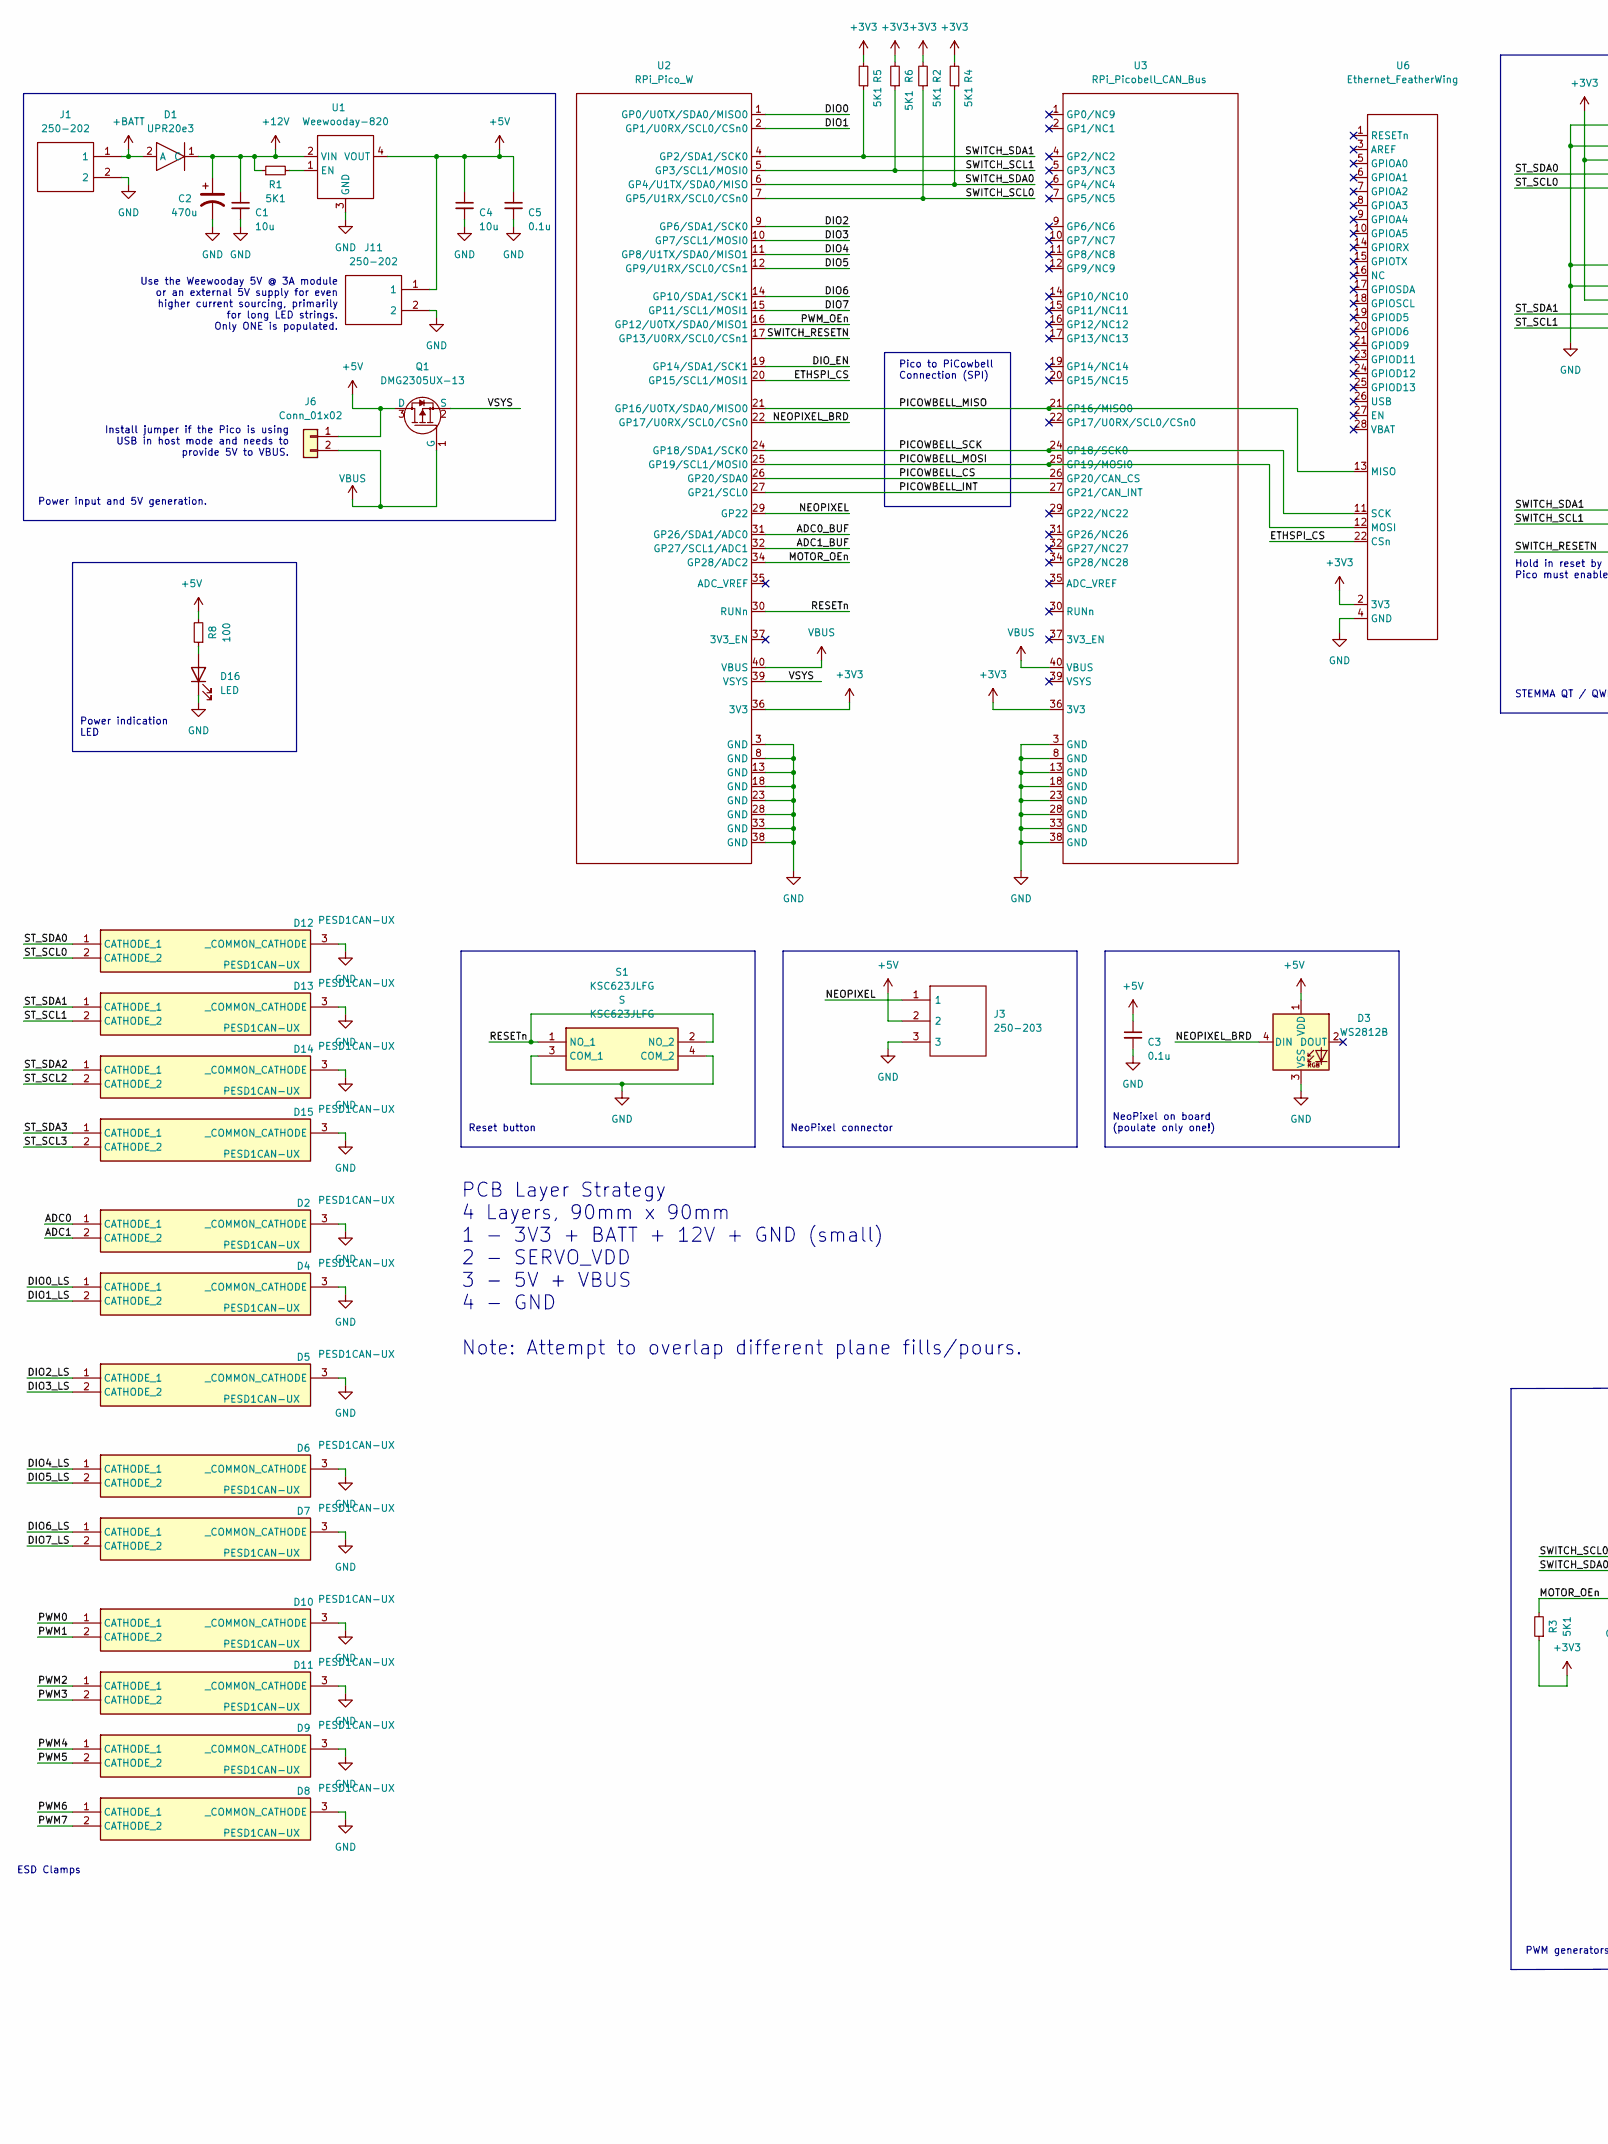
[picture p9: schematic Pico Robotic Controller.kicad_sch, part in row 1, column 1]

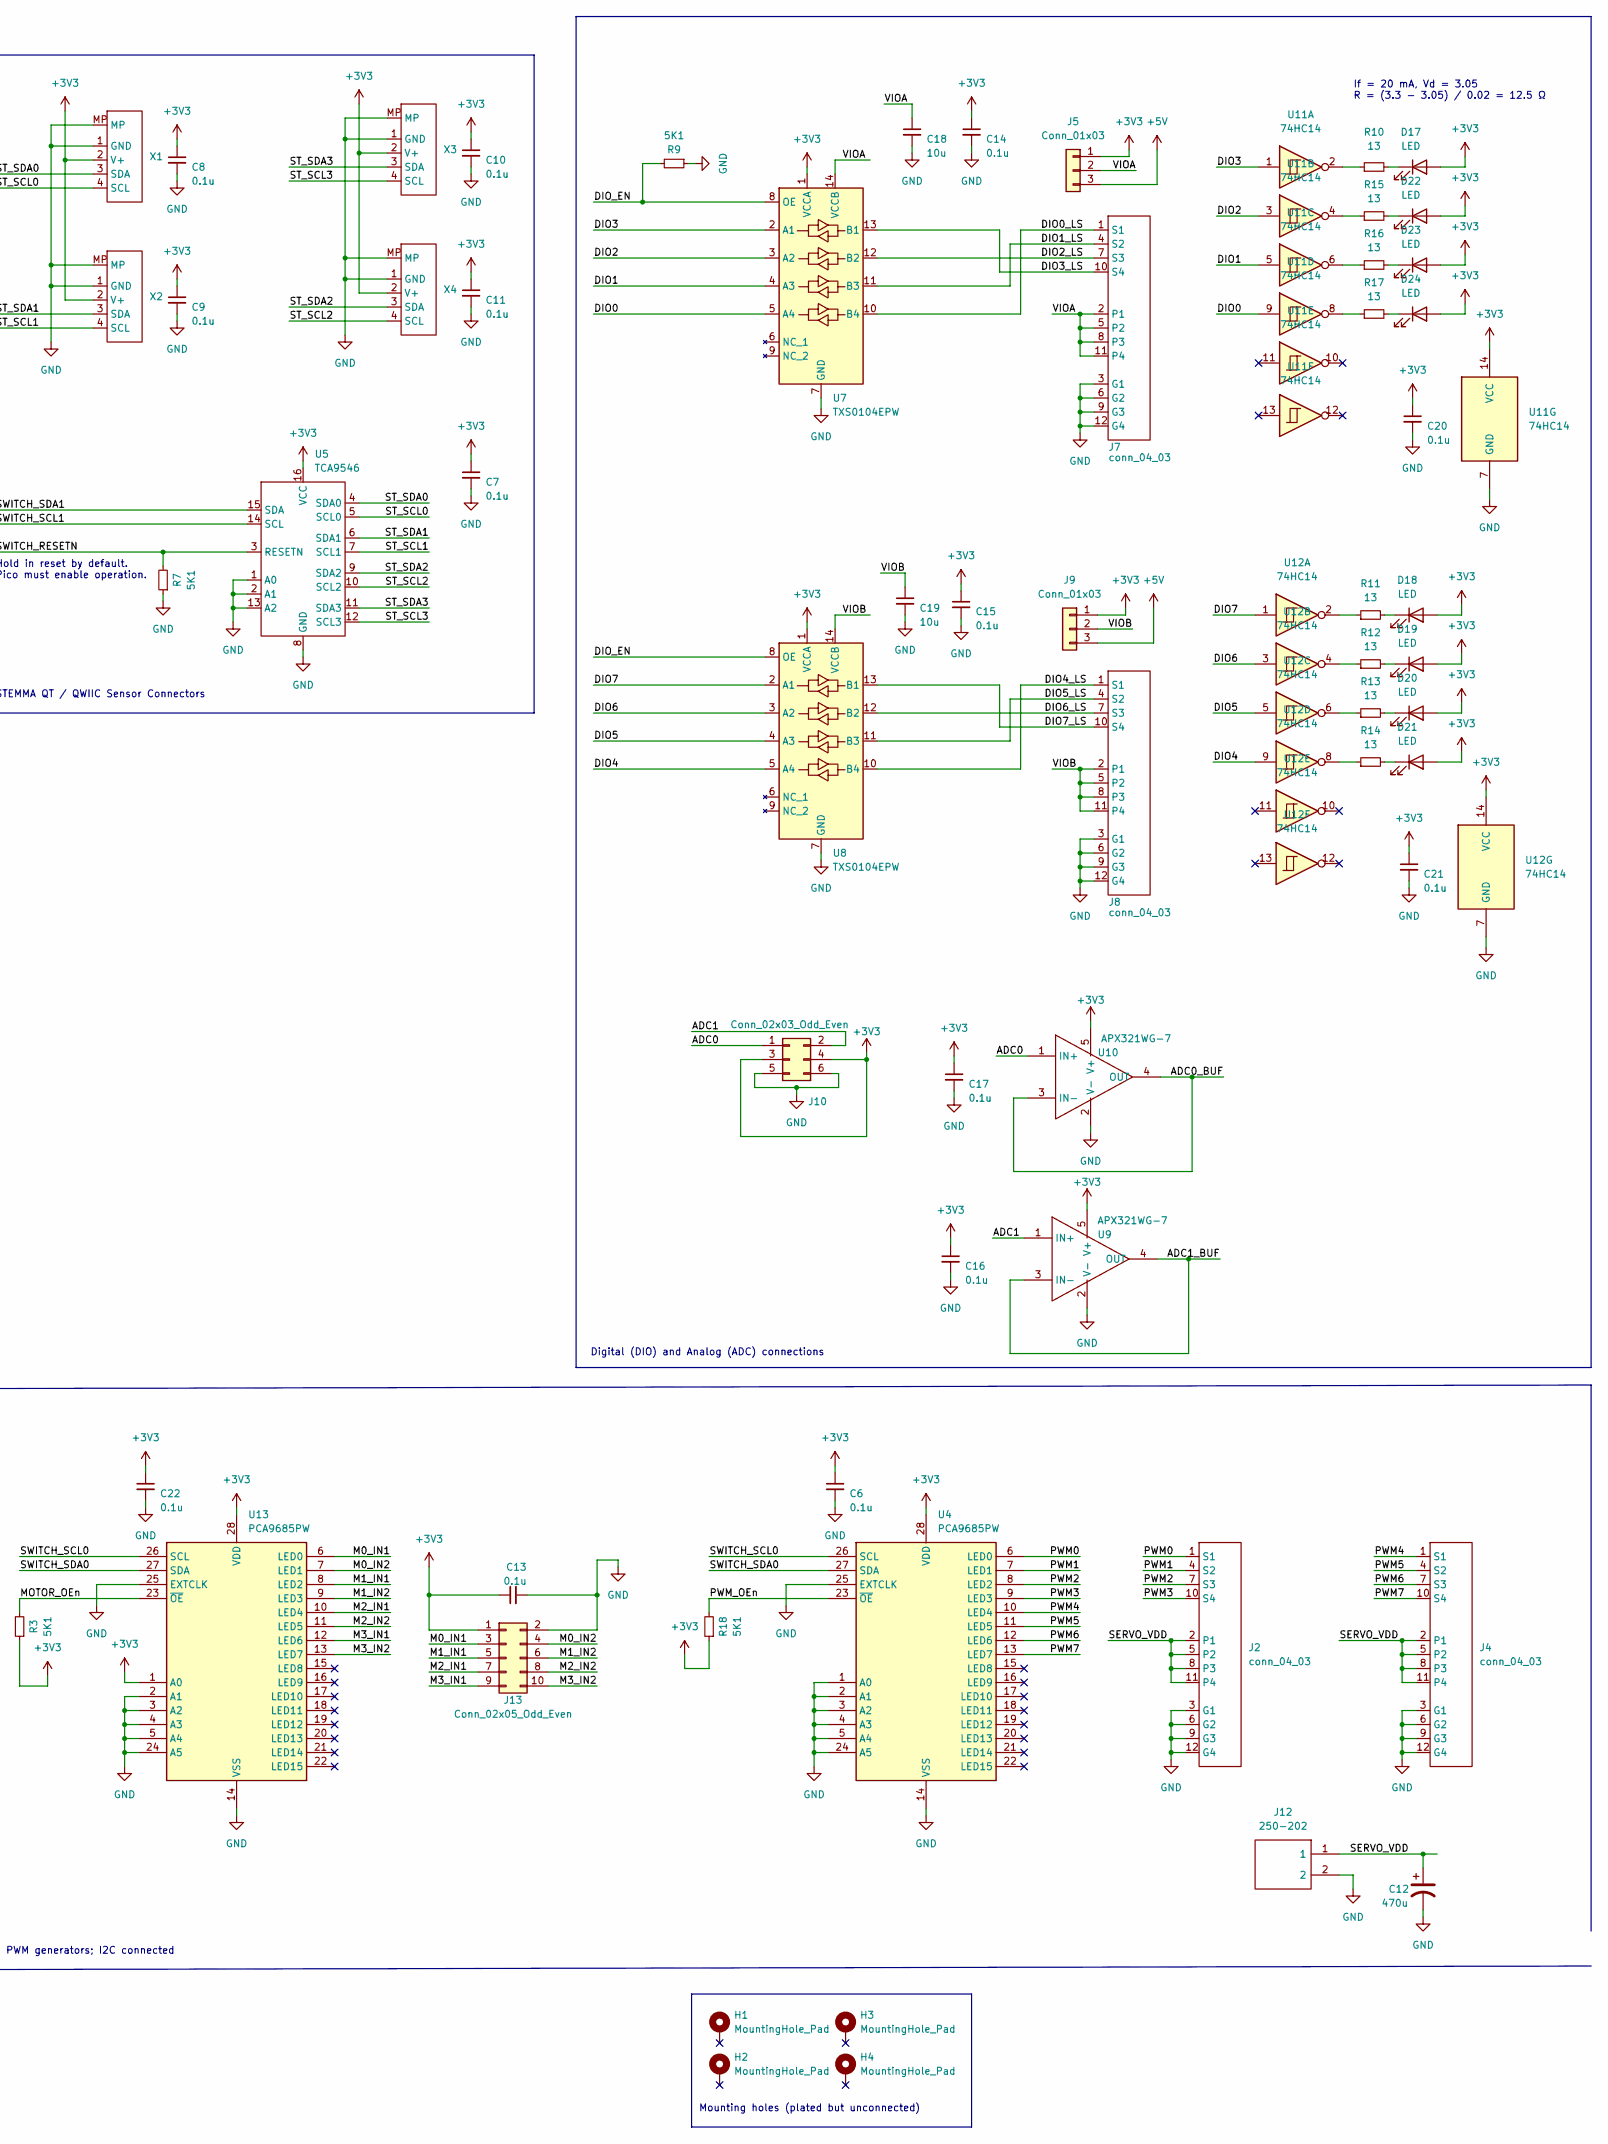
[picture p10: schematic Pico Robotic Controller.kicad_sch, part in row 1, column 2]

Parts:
C1, C4: 10u; C_1206_3216Metric; LCSC C14860
C2, C12: 470u; CAPAE830X1050N; LCSC C340767
C3, C5, C6, C7, C8, C9, C10, C11, C13, C14, C15, C16, C17, C20, C21, C22: 0.1u; C_1206_3216Metric; LCSC C24497
C18, C19: 10u; C_1206_3216Metric; LCSC C24497
D1: UPR20e3; DO-216
D2, D4, D5, D6, D7, D8, D9, D10, D11, D12, D13, D14, D15: PESD1CAN-UX; PESD1CANUX; Mouser Part Number 771-PESD1CANUX
D3: WS2812B; LED_WS2812B_PLCC4_5.0x5.0mm_P3.2mm; LCSC C2761795
D16: LED; LED_1206_3216Metric; LCSC C375581
D17, D18, D19, D20, D21, D22, D23, D24: LED; LED_0603_1608Metric; LCSC C779453
H1, H2, H3, H4: MountingHole_Pad; MountingHole_2.2mm_M2_Pad
J1, J11, J12: 250-202; 250202; Manufacturer_Part_Number 250-202
J2, J4, J7, J8: conn_04_03; conn_04x03
J3: 250-203; 250-203_1; Manufacturer_Part_Number 250-203
J5, J9: Conn_01x03; PinHeader_1x03_P2.54mm_Vertical
J6: Conn_01x02; PinHeader_1x02_P2.54mm_Vertical
J10: Conn_02x03_Odd_Even; PinHeader_2x03_P2.54mm_Vertical
J13: Conn_02x05_Odd_Even; PinHeader_2x05_P2.54mm_Vertical
Q1: DMG2305UX-13; SOT96P240X120-3N; MPN DMG2305UX-13; Digi-Key_PN DMG2305UX-13DICT-ND
R1, R2, R3, R4, R5, R6, R7, R9, R18: 5K1; R_1206_3216Metric; LCSC C118077
R8: 100; R_1206_3216Metric; LCSC C17901
R10, R11, R12, R13, R14, R15, R16, R17: 13; R_0603_1608Metric; LCSC C365384
S1: KSC623JLFG; Mouser Part Number 611-KSC623JLFG
U1: Weewooday-820
U2: RPi_Pico_W; RPi Pico W
U3: RPi_Picobell_CAN_Bus; RPi Pico W
U4, U13: PCA9685PW; TSSOP-28_4.4x9.7mm_P0.65mm; LCSC C2678753
U5: TCA9546; TSSOP-16_4.4x5mm_P0.65mm; LCSC C201653
U6: Ethernet_FeatherWing; Feather_M4_CAN_Express
U7, U8: TXS0104EPW; TSSOP-14_4.4x5mm_P0.65mm; LCSC C44955
U9, U10: APX321WG-7; SOT95P285X145-5N; Manufacturer_Part_Number APX321WG-7; Mouser Part Number 621-APX321WG-7
U11, U12: 74HC14; TSSOP-14_4.4x5mm_P0.65mm; LCSC C2866133
X1, X2, X3, X4: STEMMA_I2C_QT; JST_SH_BM04B-SRSS-TB_1x04-1MP_P1.00mm_Vertical; LCSC C545725

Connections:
+3V3: C6.1, C7.1, C8.1, C9.1, C10.1, C11.1, C13.1, C14.1, C15.1, C16.1, C17.1, C20.1, C21.1, C22.1, D17.2 (A), D18.2 (A), D19.2 (A), D20.2 (A), D21.2 (A), D22.2 (A), D23.2 (A), D24.2 (A), J5.1, J9.1, J10.3, J10.4, J13.1, R2.2, R3.1, R4.2, R5.2, R6.2, R18.1, U2.36 (3V3), U3.36 (3V3), U4.28 (VDD), U5.16 (VCC), U6.2 (3V3), U7.1 (VCCA), U8.1 (VCCA), U9.5 (V+), U10.5 (V+), U11.14 (VCC), U12.14 (VCC), U13.1 (A0), U13.28 (VDD), X1.2 (V+), X2.2 (V+), X3.2 (V+), X4.2 (V+)
+5V: C3.1, C4.1, C5.1, D3.1 (VDD), J3.2, J5.3, J6.1, J9.3, J11.1, Q1.3 (D), R8.2, U1.4 (VOUT)
+12V: C1.1, C2.1, D1.1 (C), R1.1, U1.2 (VIN)
+BATT: D1.2 (A), J1.1
/ADC0: D2.1 (CATHODE_1), J10.1, U10.1 (IN+)
/ADC0_BUF: U2.31 (GP26/SDA1/ADC0), U10.3 (IN-), U10.4 (OUT)
/ADC1: D2.2 (CATHODE_2), J10.2, U9.1 (IN+)
/ADC1_BUF: U2.32 (GP27/SCL1/ADC1), U9.3 (IN-), U9.4 (OUT)
/DIO0: U2.1 (GP0/U0TX/SDA0/MISO0), U7.5 (A4), U11.9
/DIO0_LS: D4.1 (CATHODE_1), J7.1 (S1), U7.10 (B4)
/DIO1: U2.2 (GP1/U0RX/SCL0/CSn0), U7.4 (A3), U11.5
/DIO1_LS: D4.2 (CATHODE_2), J7.4 (S2), U7.11 (B3)
/DIO2: U2.9 (GP6/SDA1/SCK0), U7.3 (A2), U11.3
/DIO2_LS: D5.1 (CATHODE_1), J7.7 (S3), U7.12 (B2)
/DIO3: U2.10 (GP7/SCL1/MOSI0), U7.2 (A1), U11.1
/DIO3_LS: D5.2 (CATHODE_2), J7.10 (S4), U7.13 (B1)
/DIO4: U2.11 (GP8/U1TX/SDA0/MISO1), U8.5 (A4), U12.9
/DIO4_LS: D6.1 (CATHODE_1), J8.1 (S1), U8.10 (B4)
/DIO5: U2.12 (GP9/U1RX/SCL0/CSn1), U8.4 (A3), U12.5
/DIO5_LS: D6.2 (CATHODE_2), J8.4 (S2), U8.11 (B3)
/DIO6: U2.14 (GP10/SDA1/SCK1), U8.3 (A2), U12.3
/DIO6_LS: D7.1 (CATHODE_1), J8.7 (S3), U8.12 (B2)
/DIO7: U2.15 (GP11/SCL1/MOSI1), U8.2 (A1), U12.1
/DIO7_LS: D7.2 (CATHODE_2), J8.10 (S4), U8.13 (B1)
/DIO_EN: R9.2, U2.19 (GP14/SDA1/SCK1), U7.8 (OE), U8.8 (OE)
/ETHSPI_CS: U2.20 (GP15/SCL1/MOSI1), U6.22 (CSn)
/M0_IN1: J13.3, U13.6 (LED0)
/M0_IN2: J13.4, U13.7 (LED1)
/M1_IN1: J13.5, U13.8 (LED2)
/M1_IN2: J13.6, U13.9 (LED3)
/M2_IN1: J13.7, U13.10 (LED4)
/M2_IN2: J13.8, U13.11 (LED5)
/M3_IN1: J13.9, U13.12 (LED6)
/M3_IN2: J13.10, U13.13 (LED7)
/MOTOR_OEn: R3.2, U2.34 (GP28/ADC2), U13.23 (~OE)
/NEOPIXEL: J3.1, U2.29 (GP22)
/NEOPIXEL_BRD: D3.4 (DIN), U2.22 (GP17/U0RX/SCL0/CSn0)
/PICOWBELL_CS: U2.26 (GP20/SDA0), U3.26 (GP20/CAN_CS)
/PICOWBELL_INT: U2.27 (GP21/SCL0), U3.27 (GP21/CAN_INT)
/PICOWBELL_MISO: U2.21 (GP16/U0TX/SDA0/MISO0), U3.21 (GP16/MISO0), U6.13 (MISO)
/PICOWBELL_MOSI: U2.25 (GP19/SCL1/MOSI0), U3.25 (GP19/MOSI0), U6.12 (MOSI)
/PICOWBELL_SCK: U2.24 (GP18/SDA1/SCK0), U3.24 (GP18/SCK0), U6.11 (SCK)
/PWM0: D10.1 (CATHODE_1), J2.1 (S1), U4.6 (LED0)
/PWM1: D10.2 (CATHODE_2), J2.4 (S2), U4.7 (LED1)
/PWM2: D11.1 (CATHODE_1), J2.7 (S3), U4.8 (LED2)
/PWM3: D11.2 (CATHODE_2), J2.10 (S4), U4.9 (LED3)
/PWM4: D9.1 (CATHODE_1), J4.1 (S1), U4.10 (LED4)
/PWM5: D9.2 (CATHODE_2), J4.4 (S2), U4.11 (LED5)
/PWM6: D8.1 (CATHODE_1), J4.7 (S3), U4.12 (LED6)
/PWM7: D8.2 (CATHODE_2), J4.10 (S4), U4.13 (LED7)
/PWM_OEn: R18.2, U2.16 (GP12/U0TX/SDA0/MISO1), U4.23 (~OE)
/RESETn: S1.1 (NO_1), S1.2 (NO_2), U2.30 (RUNn)
/SERVO_VDD: C12.1, J2.2 (P1), J2.5 (P2), J2.8 (P3), J2.11 (P4), J4.2 (P1), J4.5 (P2), J4.8 (P3), J4.11 (P4), J12.1
/ST_SCL0: D12.2 (CATHODE_2), U5.5 (SCL0), X1.4 (SCL)
/ST_SCL1: D13.2 (CATHODE_2), U5.7 (SCL1), X2.4 (SCL)
/ST_SCL2: D14.2 (CATHODE_2), U5.10 (SCL2), X4.4 (SCL)
/ST_SCL3: D15.2 (CATHODE_2), U5.12 (SCL3), X3.4 (SCL)
/ST_SDA0: D12.1 (CATHODE_1), U5.4 (SDA0), X1.3 (SDA)
/ST_SDA1: D13.1 (CATHODE_1), U5.6 (SDA1), X2.3 (SDA)
/ST_SDA2: D14.1 (CATHODE_1), U5.9 (SDA2), X4.3 (SDA)
/ST_SDA3: D15.1 (CATHODE_1), U5.11 (SDA3), X3.3 (SDA)
/SWITCH_RESETN: R7.2, U2.17 (GP13/U0RX/SCL0/CSn1), U5.3 (RESETN)
/SWITCH_SCL0: R2.1, U2.7 (GP5/U1RX/SCL0/CSn0), U4.26 (SCL), U13.26 (SCL)
/SWITCH_SCL1: R6.1, U2.5 (GP3/SCL1/MOSI0), U5.14 (SCL)
/SWITCH_SDA0: R4.1, U2.6 (GP4/U1TX/SDA0/MISO), U4.27 (SDA), U13.27 (SDA)
/SWITCH_SDA1: R5.1, U2.4 (GP2/SDA1/SCK0), U5.15 (SDA)
/VIOA: C18.1, J5.2, J7.2 (P1), J7.5 (P2), J7.8 (P3), J7.11 (P4), U7.14 (VCCB)
/VIOB: C19.1, J8.2 (P1), J8.5 (P2), J8.8 (P3), J8.11 (P4), J9.2, U8.14 (VCCB)
/VSYS: Q1.2 (S), U2.39 (VSYS)
GND: C1.2, C2.2, C3.2, C4.2, C5.2, C6.2, C7.2, C8.2, C9.2, C10.2, C11.2, C12.2, C13.2, C14.2, C15.2, C16.2, C17.2, C18.2, C19.2, C20.2, C21.2, C22.2, D2.3 (_COMMON_CATHODE), D3.3 (VSS), D4.3 (_COMMON_CATHODE), D5.3 (_COMMON_CATHODE), D6.3 (_COMMON_CATHODE), D7.3 (_COMMON_CATHODE), D8.3 (_COMMON_CATHODE), D9.3 (_COMMON_CATHODE), D10.3 (_COMMON_CATHODE), D11.3 (_COMMON_CATHODE), D12.3 (_COMMON_CATHODE), D13.3 (_COMMON_CATHODE), D14.3 (_COMMON_CATHODE), D15.3 (_COMMON_CATHODE), D16.1 (K), J1.2, J2.3 (G1), J2.6 (G2), J2.9 (G3), J2.12 (G4), J3.3, J4.3 (G1), J4.6 (G2), J4.9 (G3), J4.12 (G4), J7.3 (G1), J7.6 (G2), J7.9 (G3), J7.12 (G4), J8.3 (G1), J8.6 (G2), J8.9 (G3), J8.12 (G4), J10.5, J10.6, J11.2, J12.2, J13.2, R7.1, R9.1, S1.3 (COM_1), S1.4 (COM_2), U1.3 (GND), U2.3 (GND), U2.8 (GND), U2.13 (GND), U2.18 (GND), U2.23 (GND), U2.28 (GND), U2.33 (GND), U2.38 (GND), U3.3 (GND), U3.8 (GND), U3.13 (GND), U3.18 (GND), U3.23 (GND), U3.28 (GND), U3.33 (GND), U3.38 (GND), U4.1 (A0), U4.2 (A1), U4.3 (A2), U4.4 (A3), U4.5 (A4), U4.14 (VSS), U4.24 (A5), U4.25 (EXTCLK), U5.1 (A0), U5.2 (A1), U5.8 (GND), U5.13 (A2), U6.4 (GND), U7.7 (GND), U8.7 (GND), U9.2 (V-), U10.2 (V-), U11.7 (GND), U12.7 (GND), U13.2 (A1), U13.3 (A2), U13.4 (A3), U13.5 (A4), U13.14 (VSS), U13.24 (A5), U13.25 (EXTCLK), X1.1 (GND), X1.MP, X2.1 (GND), X2.MP, X3.1 (GND), X3.MP, X4.1 (GND), X4.MP
unnamed: D16.2 (A), R8.1
unnamed: D17.1 (K), R10.2
unnamed: D18.1 (K), R11.2
unnamed: D19.1 (K), R12.2
unnamed: D20.1 (K), R13.2
unnamed: D21.1 (K), R14.2
unnamed: D22.1 (K), R15.2
unnamed: D23.1 (K), R16.2
unnamed: D24.1 (K), R17.2
unnamed: R1.2, U1.1 (EN)
unnamed: R10.1, U11.2
unnamed: R11.1, U12.2
unnamed: R12.1, U12.4
unnamed: R13.1, U12.6
unnamed: R14.1, U12.8
unnamed: R15.1, U11.4
unnamed: R16.1, U11.6
unnamed: R17.1, U11.8
VBUS: J6.2, Q1.1 (G), U2.40 (VBUS), U3.40 (VBUS)

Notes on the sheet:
Power input and 5V generation.
Reset button
Use the Weewooday 5V @ 3A module or an external 5V supply for even higher current sourcing, primarily for long LED strings. Only ONE is populated.
Pico to PiCowbell Connection (SPI)
Hold in reset by default. Pico must enable operation.
Power indication LED
NeoPixel on board (poulate only one!)
Install jumper if the Pico is using USB in host mode and needs to provide 5V to VBUS.
If = 20 mA, Vd = 3.05 R = (3.3 - 3.05) / 0.02 = 12.5 Ω
Digital (DIO) and Analog (ADC) connections
NeoPixel connector
STEMMA QT / QWIIC Sensor Connectors
Mounting holes (plated but unconnected)
ESD Clamps
PWM generators; I2C connected
PCB Layer Strategy 4 Layers, 90mm x 90mm 1 - 3V3 + BATT + 12V + GND (small) 2 - SERVO_VDD 3 - 5V + VBUS 4 - GND Note: Attempt to overlap different plane fills/pours.

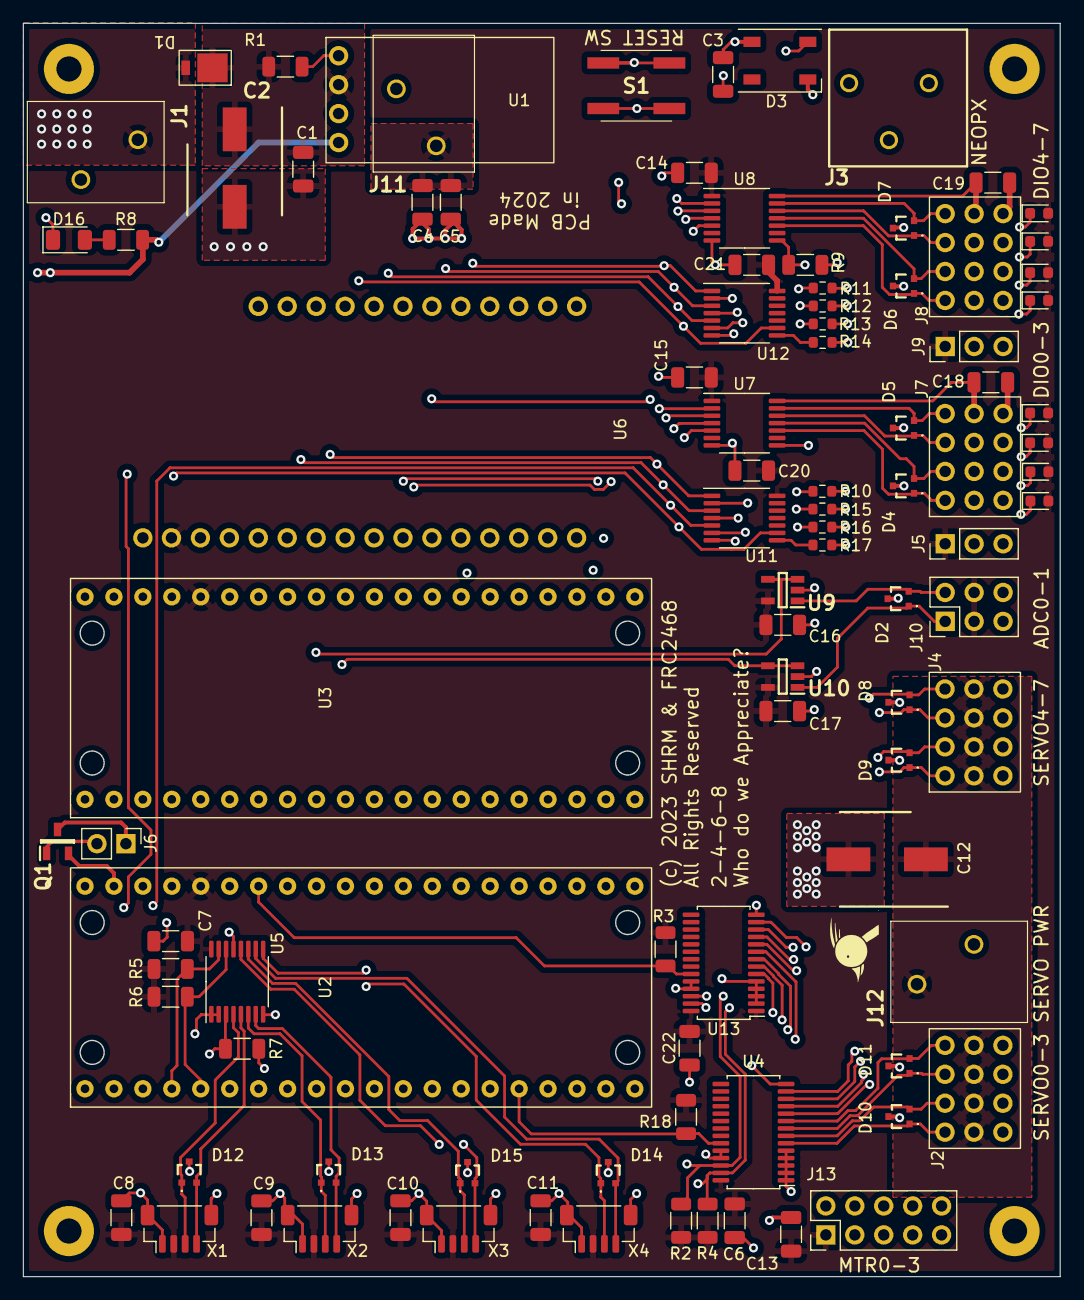
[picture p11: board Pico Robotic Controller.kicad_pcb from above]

Board: 4 copper layers, 91.0 x 110.0 mm, 100 parts (0 on the bottom side), 89 nets.

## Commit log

2023-12-28 Checkin of board files
    [Pico Robotic Controller Prev.csv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]
2023-12-29 adds PCB layer images
2023-12-29 adds schematic PDF
2023-12-30 updated the build files
    [Pico Robotic Controller-B_Cu.gbr, Pico Robotic Controller-B_Mask.gbr, Pico Robotic Controller-B_Paste.gbr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]
2023-12-30 updated design files that correct a silkscreen comment (2023 to 2024)
    [Pico Robotic Controller.kicad_pcb, Pico Robotic Controller.kicad_sch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]
2023-12-31 updated LED resistor value (13 ohms)
    [Pico Robotic Controller.kicad_sch]
2024-01-05 updated KiCAD design files to add separate OEn for motor PWM generator
    [Pico Robotic Controller.csv, Pico Robotic Controller.kicad_pcb, Pico Robotic Controller.kicad_sch]
2024-01-05 updating manufacturing files (Gerbers)
    [Pico Robotic Controller-B_Cu.gbr, Pico Robotic Controller-B_Mask.gbr, Pico Robotic Controller-B_Paste.gbr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]
2024-01-07 updated the PWM generator enables to be pull ups from pull down
    [Pico Robotic Controller.kicad_pcb, Pico Robotic Controller.kicad_sch]
2024-01-07 updated manufacturing files to match the change in pull ups
    [Pico Robotic Controller-B_Cu.gbr, Pico Robotic Controller-B_Mask.gbr, Pico Robotic Controller-B_Paste.gbr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]

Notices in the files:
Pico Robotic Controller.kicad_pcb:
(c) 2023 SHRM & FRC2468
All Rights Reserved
